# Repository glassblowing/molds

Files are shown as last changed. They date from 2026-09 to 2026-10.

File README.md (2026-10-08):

# Glassblowing mold generators

Parametric molds for hot glass, written as [build123d](https://github.com/gumyr/build123d) scripts. Each script writes ready-to-order files: STEP for a machine shop, DXF for a laser-cutting service, and STL for a look or a test print. The generated files are checked in under [`mold-designs/`](mold-designs/), so you can order parts without running anything.

> [!WARNING]
> **These are designs, not proven tools.** As far as this repository records, none of them has yet been made and used with glass. The scripts check that the parts are valid solids, fit together, and can be reached by a cutter, but nobody has confirmed how they behave at the bench. Treat the sizes as a starting point, and please report back if you build one.

## What is here

| Mold | What it does | How it is made | Script | Files |
|---|---|---|---|---|
| [Insert mold](#insert-mold) | Dip or blow mold with five swappable patterns on loose inserts | CNC milling | `pineapple_mold_generator.py` | `mold-designs/insert-mold/` |
| [Pineapple mold](#pineapple-mold) | One-piece version of the pineapple pattern | Laser-cut plates, or casting | `pineapple_mold_generator.py` | `mold-designs/pineapple/` |
| [Optic molds](#optic-molds) | Classic open dip molds: star, flower, rib, fluted, sunburst | CNC milling | `optic_mold_generator.py` | `mold-designs/optic/` |
| [Blow mold](#blow-mold) | Two-part mold for a vessel shape you draw as a profile | CNC milling | `blow_mold_generator.py` | `mold-designs/blow/` |
| [Segmented grenade mold](#segmented-grenade-mold) | Blow mold of four staves in a square tube, for a grid of raised squares | CNC milling plus stock tube | `segmented_mold_generator.py` | `mold-designs/segmented/` |

## Quick start

The only thing to install is [uv](https://docs.astral.sh/uv/). Each script declares its own dependencies and runs through its shebang:

```sh
./pineapple_mold_generator.py     # about two minutes
./optic_mold_generator.py         # every pattern
./optic_mold_generator.py star rib   # only these
./blow_mold_generator.py
./segmented_mold_generator.py
```

There is also a [just](https://just.systems/) file, so you don't have to remember the script names:

```sh
just                 # list the recipes
just all             # whatever is out of date: the molds, then the README pictures
just pineapple       # one generator: optic, blow, pineapple or segmented
just optic star rib  # only these optic patterns
just previews        # the README pictures
just force=true all  # everything, whether it is out of date or not
```

A generator is skipped when its files are newer than its script. Right after a fresh clone the file times mean nothing, so use `force=true` if you want to be sure.

- **Changing a design:** every script starts with a block of named settings in millimetres, each with a comment. Edit them and run the script again.
- **The report:** each run prints the sizes, weights, stock to buy, and the results of its checks. Read it before ordering; it warns when a setting makes a part that can't be machined or assembled.
- **Viewer:** the scripts finish by sending the parts to the [OCP CAD Viewer](https://github.com/bernhard-42/vscode-ocp-cad-viewer) for VS Code. Without the viewer running they print a connection error at the very end. The files are already written by then, so it can be ignored.
- **Pictures:** `./render_previews.py` redraws the images in this README from the generated STL files. `just all` does this after the molds.

## Insert mold

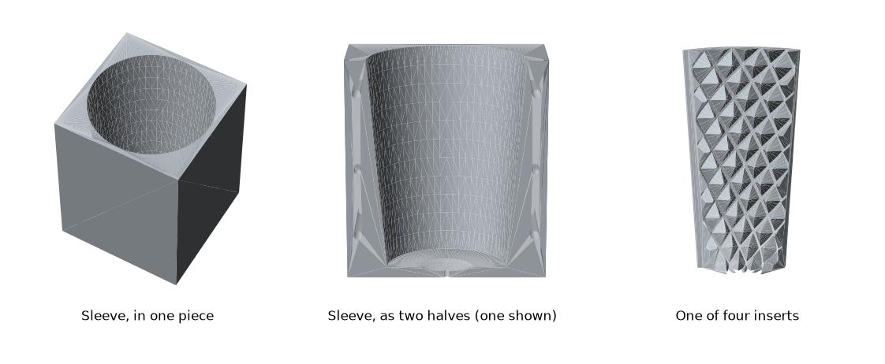
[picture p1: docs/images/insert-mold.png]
The sleeve in one piece, one half of the split sleeve, and one insert


The pattern is not cut into the mold body. It is on four identical loose inserts, each a quarter of the wall, that drop into a sleeve with a tapered bore.

- **Snug but removable:** the inserts wedge into the taper under their own weight with no play, and are free the moment they lift. Hot inserts that have grown sit a little higher instead of jamming.
- **Nothing gets stuck:** if the glass chills and grabs the pattern, pulling it out brings the inserts with it, and they pull off sideways.
- **Registered seams:** a small step down each seam laps every insert over its neighbor, so none can drop inward, yet each still pulls straight off.
- **Curved bottom:** the wall curves in like a bowl and the pattern carries on round it, so the rounded end of a bubble meets the same pattern as its sides. The sleeve's floor is dished and vented so the glass can't seal to it.
- **Swappable:** all five insert sets fit the same sleeve.

### Insert sets

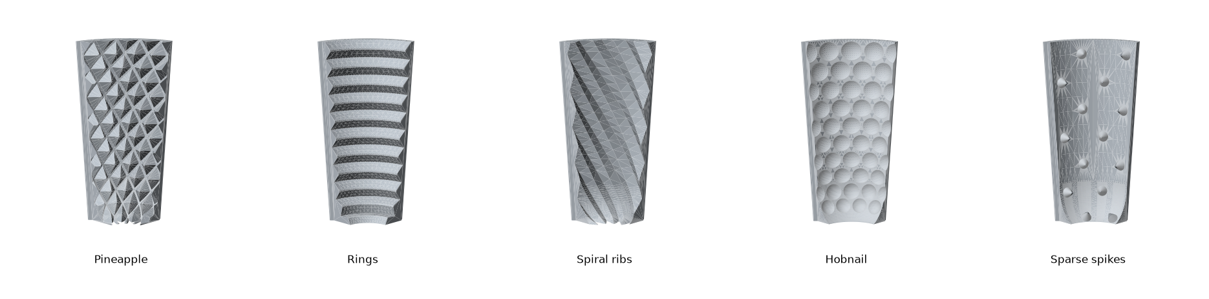
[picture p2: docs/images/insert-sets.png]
The five insert sets, seen from inside the mold


| Set | File | Pattern | In the glass | Cutter directions |
|---|---|---|---|---|
| Pineapple | `inserts/pineapple.step` | 14 rows of 16 diamond pyramids with small flat tips, about 3 to 9 mm deep, leaning into a spiral | A grid of dimples; gather over them to trap bubbles | 3 |
| Rings | `inserts/rings.step` | 11 V-shaped rings, 12 mm apart and 5 mm deep | Grooves round the piece | 2 |
| Spiral ribs | `inserts/spiral.step` | 16 ribs turning 120° from floor to rim | A swirl optic without twisting by hand | 2 |
| Hobnail | `inserts/hobnail.step` | 160 round pockets, 9 to 12.7 mm across; those on a seam are half in each insert | Rows of raised beads; blow into the mold to fill them | 2 |
| Sparse spikes | `inserts/spikes.step` | 56 cones, 7 mm tall | A few deep pits, for deliberate air-trap bubbles | 4 |

Make four of whichever set you want. "Cutter directions" is how many angles the cutter has to come from to reach the whole pattern: square-on to the insert's inside face, then turned to each side or tipped toward the floor. On a machine with a rotary axis these are index positions in one setup; on a plain 3-axis mill each is a separate tilted setup. The script works this out by line of sight and prints the share of the surface reached.

Rings and spiral ribs hold the glass against a straight pull, so expect those inserts to come out with the glass. Pineapple and spikes rely on the glass touching only the tips.

### Parts to order

| Part | Quantity | File | Stock | Notes |
|---|---|---|---|---|
| Insert | 4 of one set | `inserts/<set>.step` | about 65 × 37 × 122 mm each | The outside is the taper seat |
| Sleeve, one piece | 1 | `sleeve_solid.step` | 100 × 100 × 130 mm block | Bore is milled 126 mm deep from the top |
| Foot plate | 1 | `foot_plate_solid.dxf` | 130 × 130 × 8 mm plate | Sticks out 15 mm to stand on |
| M5 screws | 4 | | | Foot plate to the underside of the sleeve; countersink them |

The sleeve is also drawn as two halves, to quote against the one-piece version. Use one or the other:

| Part | Quantity | File | Stock | Notes |
|---|---|---|---|---|
| Sleeve half | 2 | `sleeve_half_a.step`, `sleeve_half_b.step` | 116 × 50 × 130 mm block each | Each half-bore is a trough 46 mm deep |
| Foot plate | 1 | `foot_plate_halves.dxf` | 146 × 130 × 8 mm plate | |
| M5 bolts and nuts | 4 | | at least 110 mm long | Through the split |
| Dowel pins | 2 | | 4 mm | Line the halves up |
| M5 screws | 4 | | | Foot plate |

Things to tell the shop:

- **Material:** 6061 aluminum machines cleanly and is the default. See [Materials](#materials).
- **Outside of the sleeve:** leave it as sawn. Only the bore, the floor and the holes matter.
- **Creases:** the sharp inside creases of every pattern may be left rounded to the cutter's radius. The glass never reaches them.
- **The files are true CAD surfaces, not converted meshes.** Walls are real cones, pockets real spheres, and rib flanks smooth curved surfaces. On the pineapple insert each point is a flat-sided boss with a flat tip, standing on the smooth wall with a strip of bare wall round it. Upload the `.step` files; the `.stl` files are meshes and a shop will reject them.
- **The taper:** the bore and the backs of the inserts are the same cone, 5.1° a side. An error of 0.1 mm in a diameter only moves the inserts 0.6 mm up or down, and they are designed to stand 1.5 mm clear of the floor to absorb it.
- **Split sleeve only:** the two half-bores must meet without a step.

### Size

| | |
|---|---|
| Cavity at the rim | 82 mm |
| Flat floor | 32 mm |
| Cavity depth | 124 mm |
| Opening between pineapple tips | 25 mm at the bottom, 63 mm at the rim |
| Sleeve | 100 mm square, 130 mm tall |

The main settings are `MOLD_DIAMETER`, `MOLD_HEIGHT`, `BOTTOM_RADIUS`, `FLOOR_RADIUS` and `BOWL_HEIGHT`. Each insert set has its own block of settings below those.

## Pineapple mold

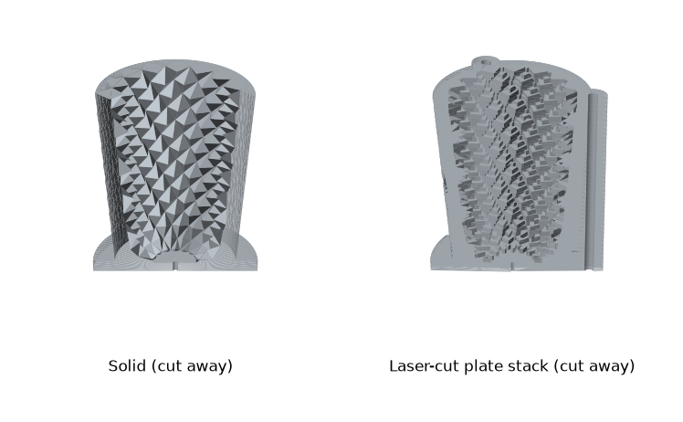
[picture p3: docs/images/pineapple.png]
The solid pineapple mold and the laser-cut plate stack, both cut away


The same pineapple cavity as the insert set, as a one-piece mold with a tapered body and a foot. It is drawn two ways.

**Laser-cut plate stack.** The cavity is sliced into flat plates that stack on threaded rods. The points come out stepped, and overhangs cost nothing because every plate is cut on its own.

| Part | Quantity | File | Notes |
|---|---|---|---|
| Plates | 41 | `plates/plate_01.dxf` to `plate_41.dxf` | 3.175 mm (1/8") sheet, up to 113 mm across, numbered from the bottom |
| M6 threaded rod | 3 | | at least 150 mm long, with nuts |

- **Order and alignment:** the rod holes are unevenly spaced, so a plate only fits one way round and one way up. Each plate also has a notch in its rim, a little further round than the one below, so a correctly ordered stack shows one diagonal line of notches.
- **Cost drivers:** 0.47 m² of sheet and 30 m of cut. The script prints these so you can compare variations.
- **Check before ordering:** the 6.4 mm rod holes and the 3.2 mm vent against your service's minimum hole size for the sheet you choose.

**Solid.** `solid.step` is one piece with true pyramids, for casting or metal printing. It cannot be milled: the points overhang, so a cutter working from above can't reach under them.

## Optic molds

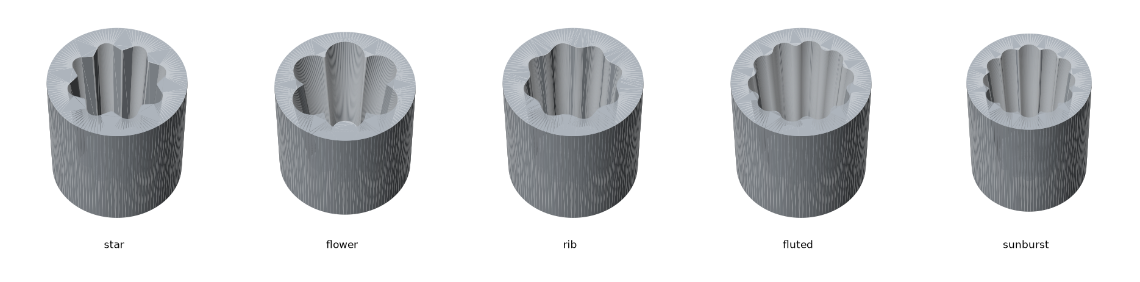
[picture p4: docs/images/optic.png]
The five optic molds


One-piece open dip molds. The gather is pushed in to take the pattern and pulled straight out, so every cavity widens toward the top with at least 3° of draft.

| Pattern | Cavity | Bar stock |
|---|---|---|
| `star` | 67 → 82 mm, 100 mm deep | 4.5" round × 118 mm |
| `flower` | 74 → 103 mm, 100 mm deep | 5" round × 118 mm |
| `rib` | 69 → 82 mm, 100 mm deep | 4.5" round × 118 mm |
| `fluted` | 68 → 87 mm, 100 mm deep | 4.5" round × 118 mm |
| `sunburst` | 58 → 77 mm, 100 mm deep | 4" round × 118 mm |

The script is built around machining cost. It rounds the pocket corners to suit the cutter you name in `TOOL_DIAMETER`, picks the smallest standard bar that leaves enough wall, and reports the largest cutter that can finish each shape and how far it has to reach.

## Blow mold

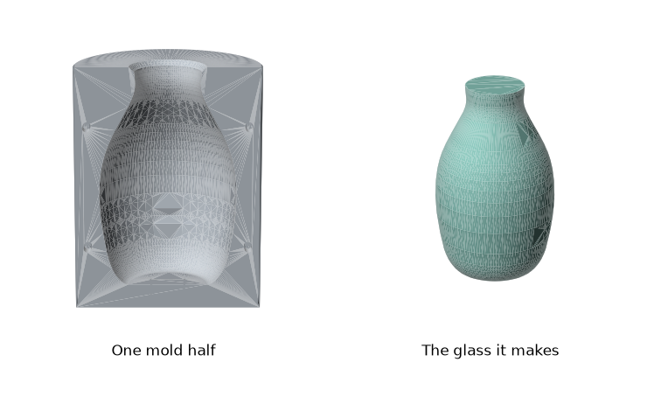
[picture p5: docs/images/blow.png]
One half of the blow mold and the glass it makes


A two-part mold for a vessel. You describe the outside of the finished piece as a list of (radius, height) points in `PROFILE`, and the script fits a smooth curve through them, scales it for shrinkage, and splits the block into two halves with dowel holes and vents.

## Segmented grenade mold

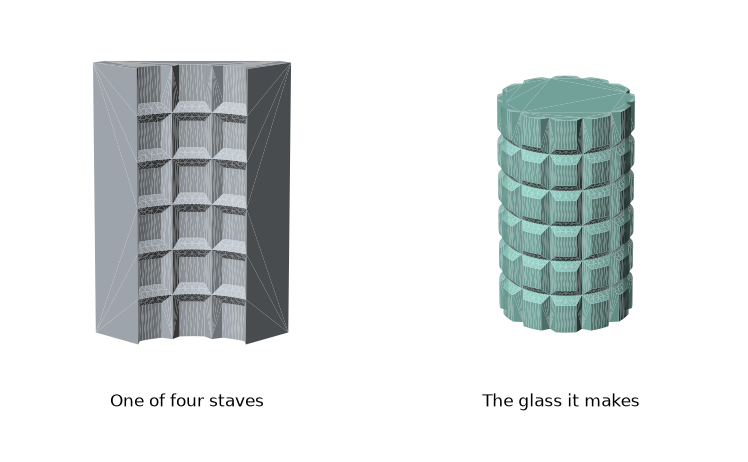
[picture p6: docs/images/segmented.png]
One stave of the segmented mold and the glass it makes


A blow mold for a grid of raised squares. Four identical staves stand in a length of square steel tube. The glass is blown out against them, and lifting the pipe brings the staves up with it so they fall away sideways. Each stave is machined square-on from its inside face.

| Part | Quantity | File | Notes |
|---|---|---|---|
| Stave | 4 | `stave.step` | from 71 × 20 × 100 mm bar |
| Square steel tube | 1 | | 3.5" × 3/16" wall, 100 mm long |
| Base plate | 1 | `base_plate.dxf` | 119 mm square, 6.35 mm; weld or bracket it to the tube |

The tube's real inside size and corner radius vary by supplier. Measure yours and adjust `TUBE_OUTER`, `TUBE_WALL` and `CORNER_RELIEF` before cutting staves.

## Materials

- **6061 aluminum:** the default for machined parts. It works even though it melts below glass working temperature, because contact is brief and aluminum carries the heat away quickly.
- **5052 aluminum:** fine for laser-cut plates, where it is a common sheet alloy. It is gummier to machine, so prefer 6061 for inserts and sleeves.
- **Mild steel:** a good choice for laser-cut plates and for anything with thin points, which stay harder when hot.
- **Never galvanized steel.** It gives off zinc fumes at glass temperatures.

Aluminum loses its hardness once it has spent time well above 200 °C, so points and edges get easier to dent with use.

## Using the molds

- **Keep contact short.** Don't let hot glass sit in a metal mold, and let the mold cool between dips. A mold that gets too hot makes glass stick; a stone-cold one leaves chill marks.
- **Glass still needs annealing.** Take the piece out as soon as it is stiff and put it away to anneal. Glass left to go cold in a metal mold will crack.
- **Loose inserts and staves come out hot.** Have tongs and somewhere safe to drop them.
- **Deep molds chill the bottom first** when the gather is simply plunged in. Blowing the bubble out against the wall makes the contact much more even.

## How the designs are checked

The scripts refuse to write parts that fail these, or print a warning in the report:

- **Valid solids:** every part is a single closed solid.
- **Release:** the optic molds and the segmented staves are checked for draft, so nothing hides behind anything else in the direction the glass or the part pulls away.
- **Fit:** four inserts must add up exactly to a full ring. This catches a pattern that doesn't repeat every quarter turn, and cuts that have gone wrong.
- **Cutter reach:** for the insert sets, the share of the patterned surface a cutter can see from the directions listed in the settings.

These are checks on geometry. They don't replace a machinist's judgement or a trial with glass.

## License

MIT. See [LICENSE](LICENSE).

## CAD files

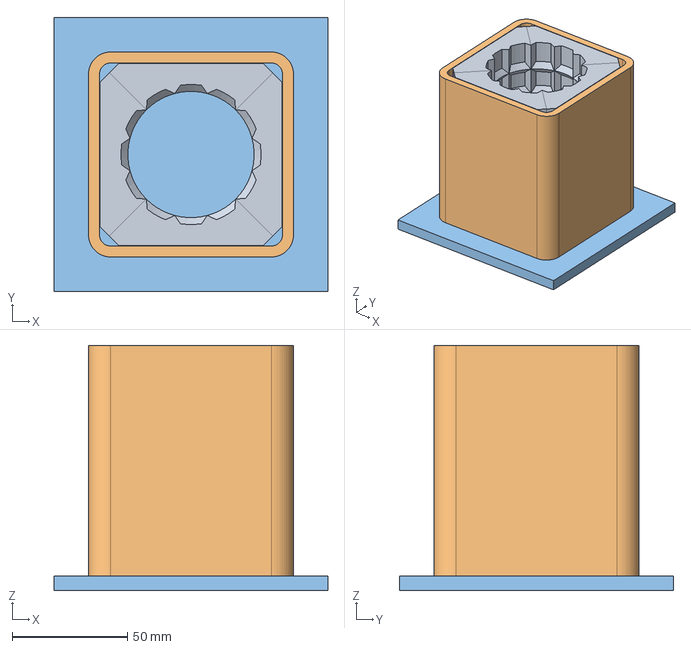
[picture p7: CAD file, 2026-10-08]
mold-designs/segmented/assembly.step
118.9 x 118.9 x 106.3 mm

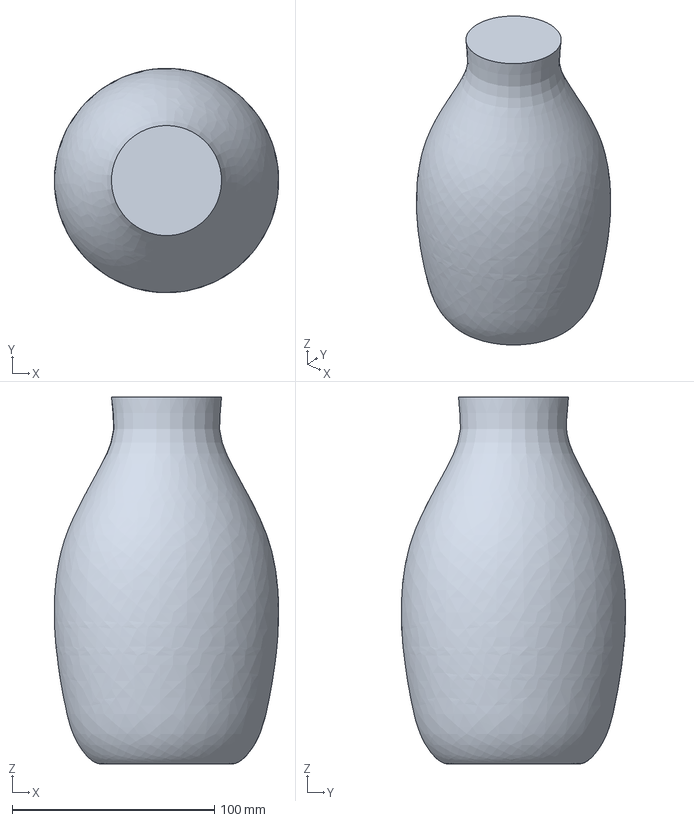
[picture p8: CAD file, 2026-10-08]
mold-designs/blow/glass_piece.step
110.8 x 110.9 x 181.3 mm

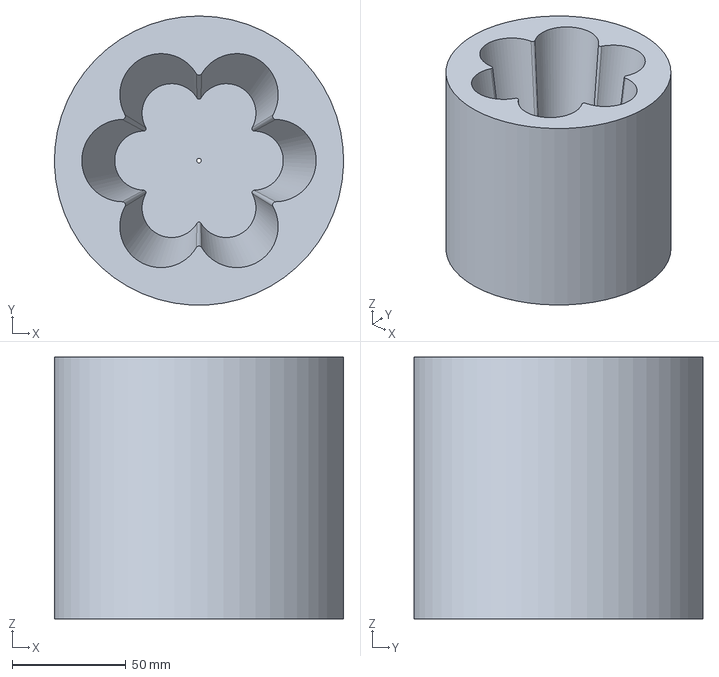
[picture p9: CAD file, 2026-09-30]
mold-designs/flower.step
126.9 x 126.9 x 115.0 mm

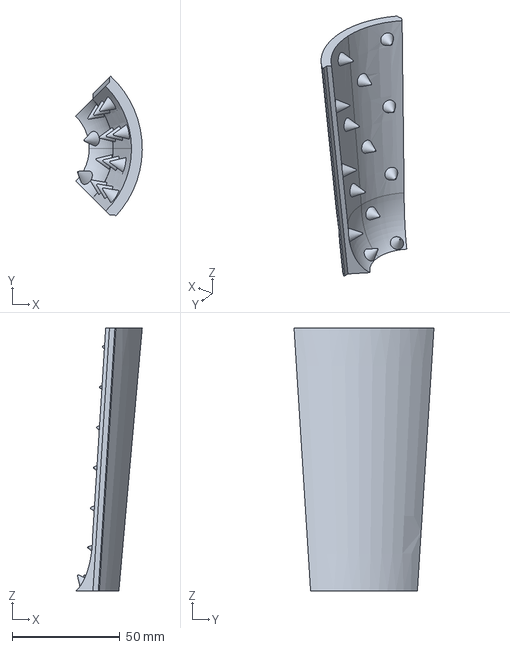
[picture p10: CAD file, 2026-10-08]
mold-designs/insert-mold/inserts/spikes.step
30.9 x 65.0 x 122.2 mm

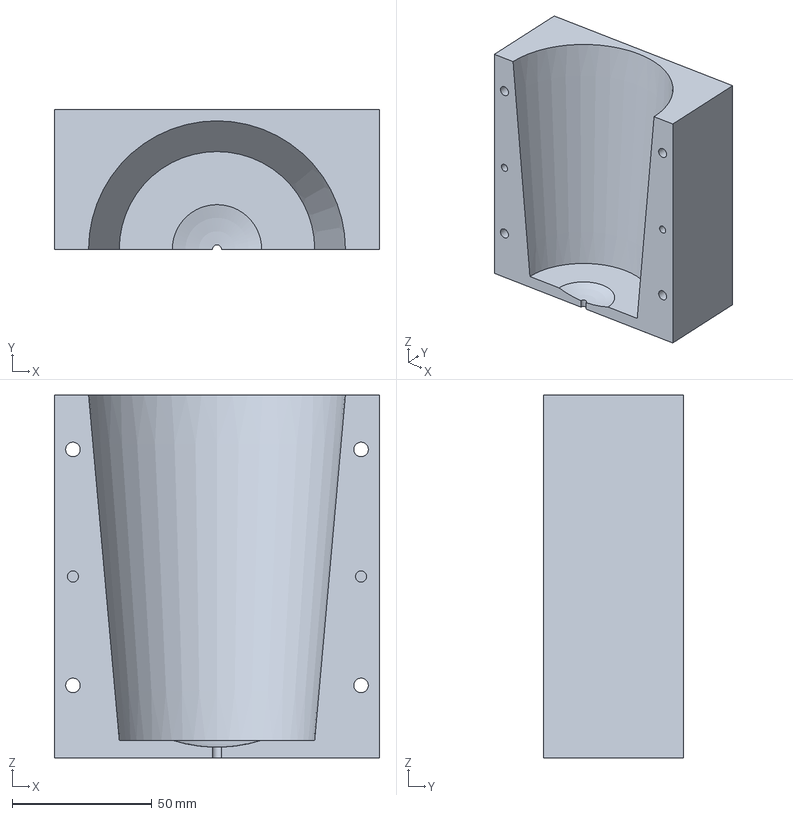
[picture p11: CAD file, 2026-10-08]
mold-designs/insert-mold/sleeve_half_b.step
116.4 x 50.0 x 130.0 mm

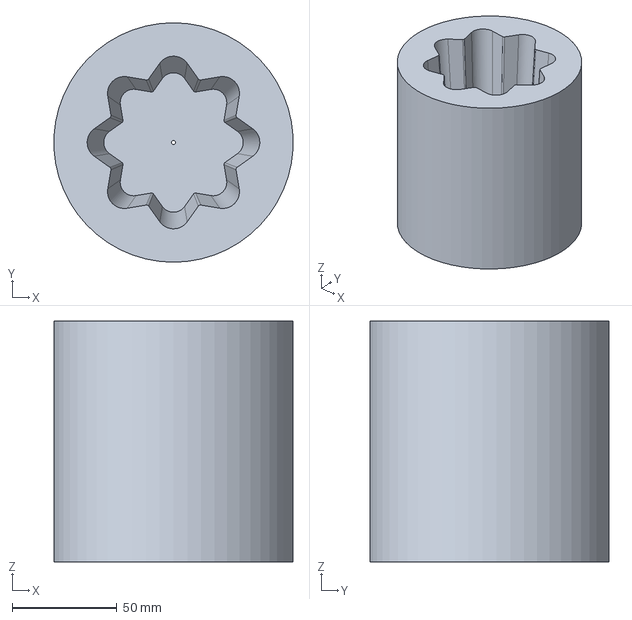
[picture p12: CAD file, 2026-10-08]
mold-designs/optic/star.step
114.1 x 114.3 x 115.0 mm

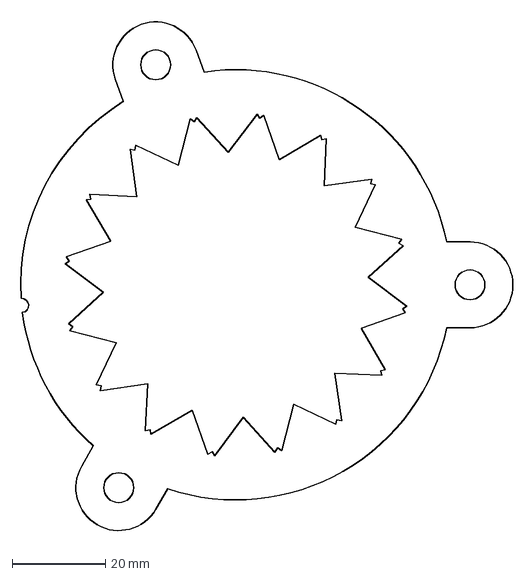
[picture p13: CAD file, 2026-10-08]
mold-designs/pineapple/plates/plate_27.dxf
106.5 x 111.5 mm

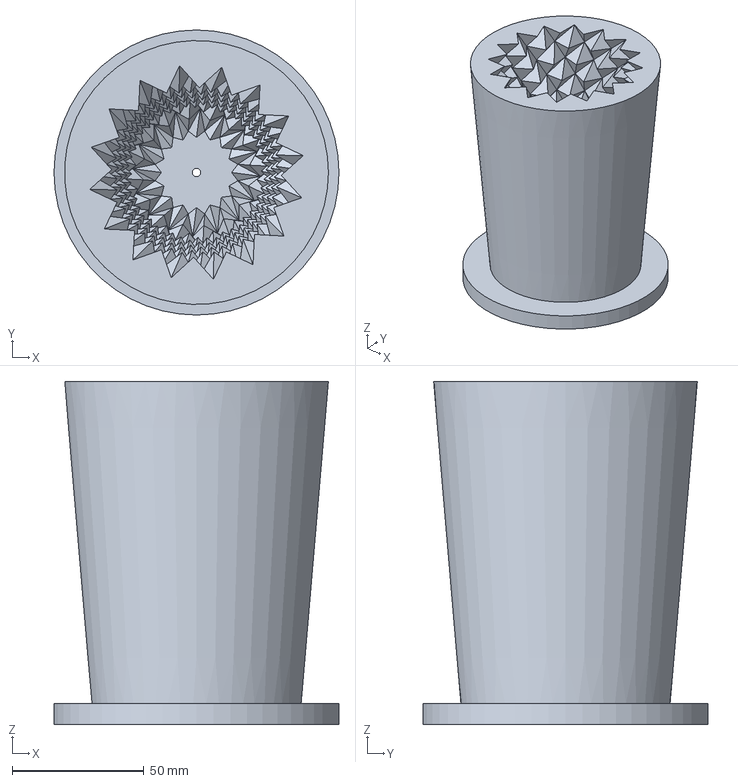
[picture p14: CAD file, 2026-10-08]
mold-designs/pineapple/solid.step
108.0 x 108.0 x 130.0 mm

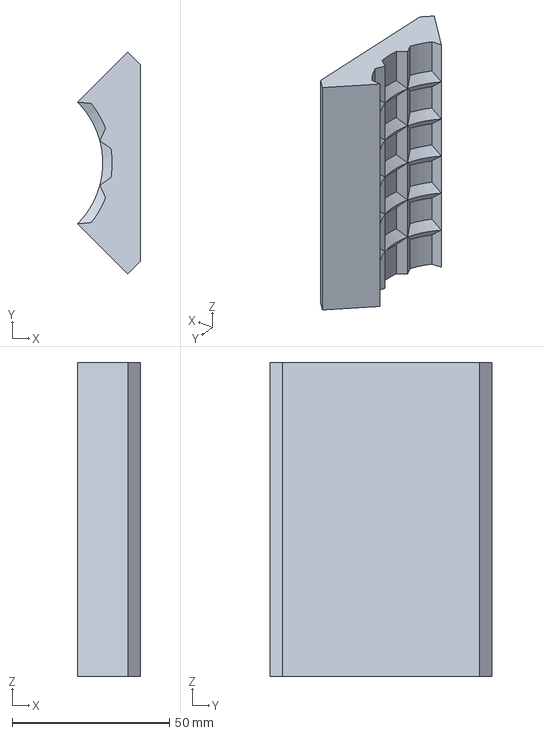
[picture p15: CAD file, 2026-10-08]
mold-designs/segmented/stave.step
20.0 x 70.8 x 100.0 mm

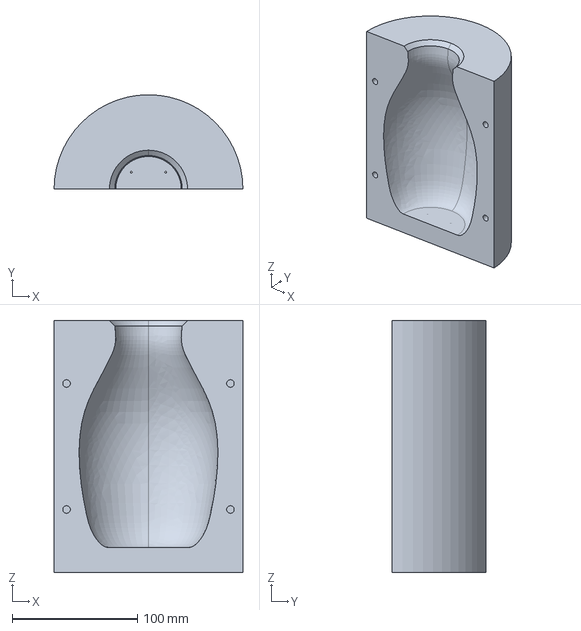
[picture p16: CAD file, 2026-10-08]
mold-designs/blow/mold_half_b.step
150.9 x 75.5 x 201.3 mm

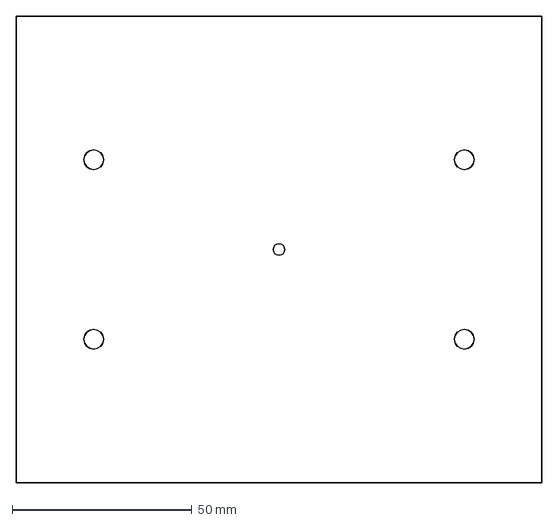
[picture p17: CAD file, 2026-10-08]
mold-designs/insert-mold/foot_plate_halves.dxf
146.4 x 130.0 mm

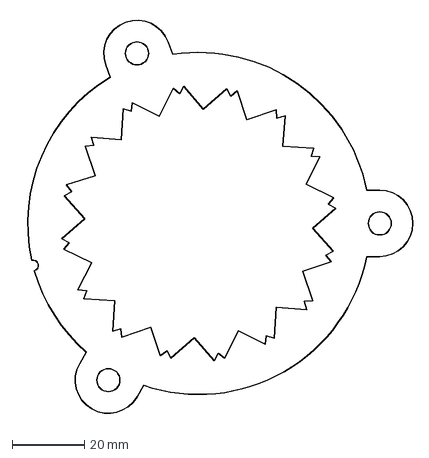
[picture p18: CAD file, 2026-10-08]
mold-designs/pineapple/plates/plate_32.dxf
110.1 x 111.5 mm

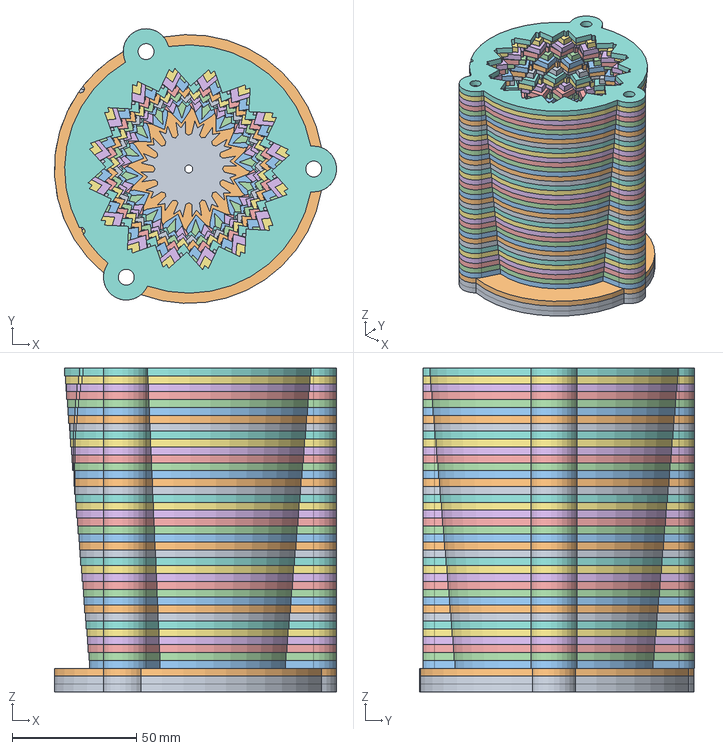
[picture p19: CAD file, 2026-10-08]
mold-designs/pineapple/stack.step
113.4 x 110.3 x 130.2 mm

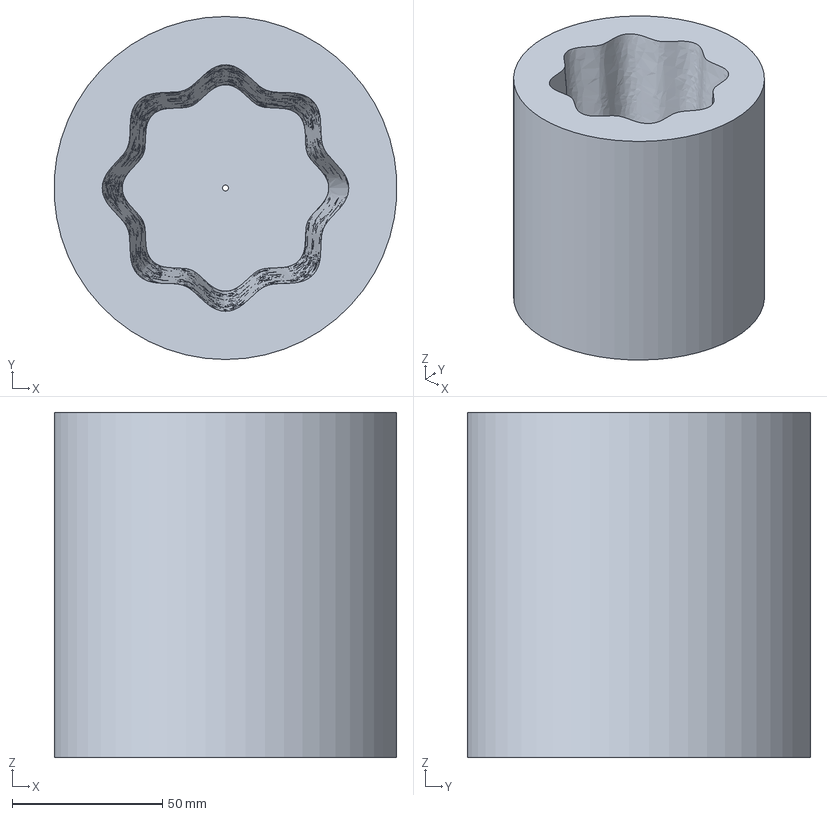
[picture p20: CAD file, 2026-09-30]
mold-designs/rib.step
114.1 x 114.3 x 115.0 mm

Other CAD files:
mold-designs/insert-mold/inserts/hobnail.step
mold-designs/optic/flower.step
mold-designs/blow/mold_half_a.step
mold-designs/insert-mold/foot_plate_solid.dxf
mold-designs/blow/glass_piece.stl
mold-designs/blow/mold_half_a.stl
mold-designs/blow/mold_half_b.stl
mold-designs/fluted.step
mold-designs/glass_piece.step
mold-designs/insert-mold/inserts/hobnail.stl
mold-designs/insert-mold/inserts/pineapple.step
mold-designs/insert-mold/inserts/pineapple.stl
mold-designs/insert-mold/inserts/rings.step
mold-designs/insert-mold/inserts/rings.stl
mold-designs/insert-mold/inserts/spikes.stl
mold-designs/insert-mold/inserts/spiral.step
mold-designs/insert-mold/inserts/spiral.stl
mold-designs/insert-mold/sleeve_half_a.step
mold-designs/insert-mold/sleeve_half_a.stl
mold-designs/insert-mold/sleeve_half_b.stl
mold-designs/insert-mold/sleeve_solid.step
mold-designs/insert-mold/sleeve_solid.stl
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

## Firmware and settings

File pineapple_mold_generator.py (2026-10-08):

#!/usr/bin/env -S uv run --python 3.13 --script --no-cache
# /// script
# requires-python = "==3.13"
# dependencies = [
#   "build123d",
#   "numpy",
#   "ocp-vscode"
# ]
# ///

"""Twisted pineapple optic mold, built with build123d.

A pineapple mold is a dip mold whose wall is covered in diamond-shaped pyramids,
packed edge to edge, that press a grid of dimples into the gather. Turning each
row a little further than the one below leans the diamonds over, so the pattern
spirals around the cavity.

The points are as deep as POINT_DEPTH asks, in the manner of cast bronze
pineapple molds: on a nearly straight wall their undersides overhang. That works
because the glass only ever touches the tips, never the wall between them, so
there is nothing for an overhang to trap. It does mean the points can't be
milled from above.

The bottom of the cavity curves in like a bowl and the points carry on round
it, shrinking as they go, so the rounded end of a bubble meets the same pattern
as its sides. Only a small flat floor is left in the middle, for the vent.

The same cavity is built four ways:

Stacked plates, for laser cutting. The cavity is sliced into flat rings, so the
pyramids come out stepped; thinner plates follow them more closely. Overhangs
cost nothing here, because every plate is cut on its own. Floor spikes can't be
cut this way, since each would be a loose island, so the base plates get a hole
at each one to tap for a cone-point set screw instead. The plates follow the
mold's taper, with a lug reaching out to each rod, which uses less sheet and
less cutting than plain discs big enough to hold the rods.

Solid, for casting or metal printing. One piece with true pyramids, a thin even
wall that tapers with the cavity, and a foot. Both are priced by the metal used.

Inserts in a sleeve, for CNC machining. The points are on four identical loose
inserts, each a quarter of the wall, that drop into a sleeve with a tapered
bore. A cutter comes at each insert from its open inside face, turned a little to
either side to get behind the points. The taper is what makes the fit work: the
inserts wedge snug under their own weight, with no play, and are free the moment
they lift. If the glass chills and grabs the points, pulling it out brings the
inserts with it and they peel off sideways. A small step down each seam laps
every insert over its neighbor, so none can drop inward, yet each still pulls
straight off. Hot inserts that have grown just sit
a little higher in the taper instead of jamming, as they would in a straight
bore. The sleeve's floor is dished, with a vent, so the glass can't seal to it.
Four more sets of inserts fit the same sleeve in place of the pineapple ones:

Rings running round the cavity.
Spiral ribs, which give a swirl without twisting the glass by hand.
Hobnail, round pockets that the glass is blown into to raise rows of beads.
Sparse spikes, a few tall points for deliberate air-trap bubbles.

Rings and spiral ribs hold the glass against a straight pull far more than
points do, which is what the loose inserts are for: they come out with the glass
and pull off sideways.

The sleeve is drawn two ways for a mill, to quote against each other: as one
square block with the bore milled down from the top, and as two blocks bolted
together, whose bore is two shallow troughs instead of one deep hole.

Rings, also for CNC machining. The solid cut into short rings that bolt together, each
shallow enough for a ball end mill to finish from above on a 3-axis machine.
Only written when the points are shallow enough not to overhang.

The outsides differ, which is fine for heat. A dip lasts a second or two, and in
that time heat gets only about 10 mm into aluminum and 5 mm into steel, so how
evenly the glass is chilled is set by the points, which are the same all the way
round. Between dips the metal evens itself out, within seconds in aluminum and
about a minute in steel. Metal further out only adds heat capacity, which slows
how fast the mold warms up over a session.

Run:
    ./pineapple_mold_generator.py

Outputs go to ./mold-designs/:
    pineapple/solid.step             the one-piece mold
    pineapple/plates/plate_NN.dxf    one cutting file per plate, numbered from the bottom
    pineapple/stack.step             the assembled plates (reference)
    pineapple/cnc_rings/ring_N.step  one part per ring, if the points allow it
    insert-mold/inserts/<set>.step   one insert of each set; make four
    insert-mold/sleeve_solid.step    the sleeve the inserts drop into, in one piece
    insert-mold/sleeve_half_X.step   the same sleeve as two halves
    insert-mold/foot_plate_*.dxf     the foot that screws under each sleeve
    *.stl                            the same parts as meshes
"""

import math
from pathlib import Path

import numpy as np

from build123d import (
    Align,
    Axis,
    Box,
    Circle,
    Compound,
    Cone,
    Cylinder,
    EllipticalCenterArc,
    ExportDXF,
    Face,
    Plane,
    Polygon,
    Polyline,
    Pos,
    Rectangle,
    Rot,
    Shell,
    Solid,
    Sphere,
    Unit,
    Vector,
    Wire,
    export_step,
    export_stl,
    extrude,
    make_face,
    revolve,
)
from ocp_vscode import show

# --- Mold (all units mm) --------------------------------------------------------
# Outside of the mold at its rim. The cavity fills it, less SOLID_WALL around the
# rim and the base underneath, and tapers down to BOTTOM_RADIUS at the floor. The
# outside tapers with it, so the wall stays about SOLID_WALL thick.
MOLD_DIAMETER = 100.0
MOLD_HEIGHT = 130.0
# Metal around the cavity, measured at the creases between points. The points
# themselves add to it, so this can be thin. In the sleeved version it is shared
# between the sleeve's rim and the inserts.
SOLID_WALL = 9.0
# Cavity wall radius the taper would reach at the floor. Smaller gives more
# taper, which is also the taper the inserts seat on.
BOTTOM_RADIUS = 30.0
# Below this height the wall curves in to meet the floor, like the bottom of a
# bowl. 0 leaves a straight wall and a flat floor.
BOWL_HEIGHT = 28.0
# Flat floor left in the middle of the bowl. The points get smaller toward it,
# so it can't shrink to nothing.
FLOOR_RADIUS = 16.0
# Flange around the bottom to stand on, so the mold stays down while the glass
# is pulled out.
FOOT_WIDTH = 15.0      # how far it sticks out past the body
FOOT_THICKNESS = 8.0
VENT_DIAMETER = 3.2    # air vent through the base; 0 to omit

# --- Pattern --------------------------------------------------------------------
POINTS_PER_ROW = 16
# Height of each diamond divided by its width, halfway up the cavity. The actual
# value is adjusted slightly so whole rows fit the cavity.
DIAMOND_ASPECT = 1.3
# How far each tip stands in from the wall, as a fraction of its diamond's width.
POINT_DEPTH = 0.6
# How far each row is turned from the row below, as a fraction of the spacing
# between points. 0.5 is the classic upright diamond; moving away from 0.5 leans
# the diamonds into a spiral, one way below 0.5 and the other way above.
TWIST_PER_ROW = 0.35
# Where the tip sits between the middle of the diamond (0) and its top corner
# (1). Raising it steepens the underside, which reduces the overhang.
TIP_LIFT = 0.0
# Grid of square pyramids on the flat floor, as wide as the bottom row's diamonds
# and as deep in proportion. Not in the sleeved version.
FLOOR_SPIKES = False

# --- Stacked plates -------------------------------------------------------------
# Sheet you will have cut. 3.175 is 1/8", stocked by most laser services in
# aluminum and mild steel, and gives each point several steps; 6.35 halves the
# plate count but leaves the points blocky. Never use galvanized steel.
PLATE_THICKNESS = 3.175
# Solid plates under the cavity floor. The solid mold's base is as thick.
BASE_PLATES = 2
# Hole through the base plates at each floor spike, to tap for a cone-point set
# screw that stands up into the cavity.
FLOOR_SCREW_TAP_DRILL = 5.0   # tap M6
# Threaded rods clamp the stack and line the plates up. The holes are unevenly
# spaced so a plate only fits one way round and one way up.
BOLT_HOLE_DIAMETER = 6.4   # close fit for M6
BOLT_ANGLES_DEG = (0, 110, 240)
EDGE_MARGIN = 6.0          # metal between a bolt hole and the cavity or the rim
# Each plate gets a notch in its rim, a little further round than the plate
# below, so a correctly ordered stack shows one diagonal line of notches.
NOTCH_RADIUS = 1.5
NOTCH_START_DEG = 140
NOTCH_SPAN_DEG = 70        # must stay between two bolt holes

# --- Inserts in a sleeve, for CNC machining -------------------------------------
# Loose inserts the wall is divided into. POINTS_PER_ROW must be a multiple of
# this, so that they are all the same part.
INSERT_COUNT = 4
# Sleeve wall at the rim. The sleeve's outside is straight, so its wall is
# thicker lower down. The rest of SOLID_WALL is the thickness of the inserts.
SLEEVE_RIM_WALL = 4.0
# For the sleeve made as two halves: bolts through the split, in a flange down
# each side of the bore, at these fractions of the mold's height. A dowel pin
# sits between them on each side. The inserts' seams don't line up with the split.
SLEEVE_BOLT_HOLE_DIAMETER = 5.2   # close fit for M5
SLEEVE_BOLT_HEIGHTS = (0.2, 0.85)
SLEEVE_DOWEL_DIAMETER = 4.0
SLEEVE_DOWEL_DEPTH = 8.0          # into each half
# Size of the step in each seam, halfway through the insert's wall. On one side
# of an insert it is a lip, on the other a matching rebate. Its faces run along
# and across the directions the two inserts pull off in, so it never binds, and
# the cutter that does the points can cut it.
SEAM_STEP = 2.5
# How far the inserts stand clear of the sleeve's floor when seated, so that the
# taper locates them and not the floor. It also absorbs error in the diameters.
INSERT_FLOOR_GAP = 1.5
FLOOR_DISH = 2.5       # how deep the sleeve's floor is dished at the middle
# Directions the cutter comes at an insert from, each as (turn, tip) in degrees.
# Turn is to either side of square-on to the insert's inside face, about the
# mold's axis; more turns reach further behind the points. Tip is down toward
# the floor. Each direction is another index of a rotary axis or another tilted
# setup.
INSERT_TOOL_DIRECTIONS_DEG = ((0, 0), (-40, 0), (40, 0))
# On the inserts each point is a separate flat-sided boss standing on the smooth
# wall, not a facet of a wall made entirely of triangles. Shops reject the
# all-triangle form as an unmeasurable mesh. A strip of bare wall is left round
# every point, this share of the diamond's width, which is also where the cutter
# runs; and the tip is cut off flat, this share of the way down, so it doesn't
# fold over.
POINT_GAP = 0.15
POINT_TIP_FLAT = 0.1

# --- Ring inserts ---------------------------------------------------------------
# A second set of inserts for the same sleeve: V-shaped rings round the cavity,
# carrying on round the bowl as circles on the bottom.
RING_PITCH = 12.0      # spacing of the rings up the wall, adjusted to fit a whole number
RING_DEPTH = 5.0       # how far each ring stands in from the wall
RING_CREST = 1.0       # flat along the top of each ring, so it doesn't chip
# Rings face the cutter all the way round, so square-on does the wall. The
# second direction, tipped down, is for the rings on the bottom of the bowl.
RING_TOOL_DIRECTIONS_DEG = ((0, 0), (0, 50))

# --- Spiral rib inserts ---------------------------------------------------------
# V-shaped ribs that wind up the wall and in across the bowl.
SPIRAL_RIBS = 16           # must be a multiple of INSERT_COUNT
SPIRAL_TURN_DEG = 120.0    # how far each rib turns about the axis from floor to rim
SPIRAL_DEPTH = 0.35        # how far a rib stands in, as a fraction of the rib spacing
SPIRAL_TOOL_DIRECTIONS_DEG = ((0, 0), (0, 50))

# --- Hobnail inserts ------------------------------------------------------------
# Round pockets in the wall, in staggered rows. Blown into, each raises a bead.
HOBNAIL_PER_ROW = 16       # must be a multiple of INSERT_COUNT
HOBNAIL_FILL = 0.8         # pocket width as a share of the spacing between pockets
# Pocket depth as a fraction of its radius. Up to about 0.4 an insert still pulls
# straight off the beads and is cut square-on; deeper pockets near the seams hook
# behind the beads, and need the cutter turned to each side.
HOBNAIL_DEPTH = 0.35
# The staggered rows put a pocket on every seam between inserts. True cuts those
# half into each insert, so the pattern runs unbroken round the glass, but each
# insert then has half-pockets running out to a sharp edge down both sides, and
# the two halves of a bead only line up as well as the inserts seat. False
# leaves those pockets out, which gives a plain stripe at each seam instead.
HOBNAIL_SPLIT_ON_SEAMS = True
HOBNAIL_TOOL_DIRECTIONS_DEG = ((0, 0), (0, 50))

# --- Sparse spike inserts -------------------------------------------------------
# A few tall cones standing square off the wall, in staggered rows.
SPIKES_PER_ROW = 8         # must be a multiple of INSERT_COUNT
SPIKE_ROW_SPACING = 18.0   # between rows, measured up the wall
SPIKE_HEIGHT = 7.0
SPIKE_BASE_DIAMETER = 7.0
SPIKE_TIP_DIAMETER = 0.6   # a small flat so the tip doesn't fold over
SPIKE_TOOL_DIRECTIONS_DEG = ((0, 0), (-40, 0), (40, 0), (0, 50))
# Holes in the underside of the sleeve for the screws that hold the foot plate.
FOOT_TAP_DRILL = 4.2       # tap M5
FOOT_TAP_DEPTH = 10.0

# --- Rings for CNC machining ----------------------------------------------------
# Used only when the points don't overhang. The pyramids are finished with a
# ball end mill working down from the top of each ring. The creases between pyramids come out rounded to the cutter's
# radius, which the glass never touches. A smaller cutter leaves crisper creases
# but reaches less far, so it needs more rings, and every ring is another part
# and another setup: this is the main cost control. 12 gives 3 rings, 6 gives 5.
CNC_TOOL_DIAMETER = 12.0
# Deepest a cutter may reach, in cutter diameters. Around 8 is a long-reach
# cutter that still cuts well; much more chatters and gets expensive.
CNC_MAX_REACH = 8.0
# Rods run through the rim wall of every ring to clamp them and line them up.
# They have to fit inside SOLID_WALL, so they are smaller than the plate stack's.
RING_BOLT_HOLE_DIAMETER = 5.2   # close fit for M5

# Density in g/cm^3 and specific heat in J/(g K), for the weight and heat
# capacity in the report. More heat capacity means the mold warms up more slowly
# over repeated dips.
MATERIALS = {"aluminum": (2.70, 0.90), "steel": (7.85, 0.49)}

OUT_DIR = Path(__file__).parent / "mold-designs"

BASE_THICKNESS = BASE_PLATES * PLATE_THICKNESS
CAVITY_DEPTH = MOLD_HEIGHT - BASE_THICKNESS
TOP_RADIUS = MOLD_DIAMETER / 2 - SOLID_WALL
CONE_SLOPE = (TOP_RADIUS - BOTTOM_RADIUS) / CAVITY_DEPTH
CONE_ANGLE_DEG = math.degrees(math.atan(CONE_SLOPE))
# The stack is built from whole plates, so it comes out within half a plate of
# MOLD_HEIGHT.
CAVITY_PLATES = round(CAVITY_DEPTH / PLATE_THICKNESS)
PLATE_COUNT = BASE_PLATES + CAVITY_PLATES
BODY_BOTTOM_RADIUS = BOTTOM_RADIUS + SOLID_WALL
INSERT_WALL = SOLID_WALL - SLEEVE_RIM_WALL
FOOT_RADIUS = BODY_BOTTOM_RADIUS + FOOT_WIDTH
FOOT_PLATES = max(1, round(FOOT_THICKNESS / PLATE_THICKNESS))
PITCH_DEG = 360 / POINTS_PER_ROW
FLOOR_EDGE = FLOOR_RADIUS if BOWL_HEIGHT > 0 else BOTTOM_RADIUS


def wall_samples():
    """The cavity wall in profile: distance along it, radius and height.

    Distance is measured up the wall from the edge of the floor. The samples run
    on straight down below the floor and up past the rim, so that rows of points
    can overhang both ends and be trimmed flat.
    """
    bowl_top = BOTTOM_RADIUS + BOWL_HEIGHT * CONE_SLOPE
    points = [(FLOOR_EDGE, -2 * MOLD_HEIGHT), (FLOOR_EDGE, 0.0)]
    if BOWL_HEIGHT > 0:
        # A quarter of an ellipse: level where it leaves the floor, upright where
        # it meets the wall.
        for a in np.linspace(0, math.pi / 2, 200)[1:]:
            points.append((
                FLOOR_EDGE + (bowl_top - FLOOR_EDGE) * math.sin(a),
                BOWL_HEIGHT * (1 - math.cos(a)),
            ))
    points.append((BOTTOM_RADIUS + 3 * MOLD_HEIGHT * CONE_SLOPE, 3.0 * MOLD_HEIGHT))
    radius, height = np.array(points).T
    along = np.concatenate([[0], np.cumsum(np.hypot(np.diff(radius), np.diff(height)))])
    return along - along[1], radius, height


WALL_ALONG, WALL_RADIUS, WALL_HEIGHT = wall_samples()
# Distance up the wall from the floor to the rim.
WALL_LENGTH = float(np.interp(CAVITY_DEPTH, WALL_HEIGHT[1:], WALL_ALONG[1:]))
# Rows are evenly spaced up the wall, as near to DIAMOND_ASPECT as a whole number
# allows, taking the diamond width halfway up the straight part.
ROWS = max(1, round(
    WALL_LENGTH
    / (DIAMOND_ASPECT / 2 * (BOTTOM_RADIUS + BOWL_HEIGHT * CONE_SLOPE + TOP_RADIUS)
       * math.sin(math.pi / POINTS_PER_ROW))
))
ROW_PITCH = WALL_LENGTH / ROWS


# --- Diamond pyramids -----------------------------------------------------------


def wall_at(along):
    """Radius and height of the wall at a distance up it from the floor."""
    return (
        float(np.interp(along, WALL_ALONG, WALL_RADIUS)),
        float(np.interp(along, WALL_ALONG, WALL_HEIGHT)),
    )


def row_radius(row):
    """Wall radius at a row's widest corners. Row 0 sits at the edge of the floor."""
    return wall_at(row * ROW_PITCH)[0]


def row_z(row):
    return wall_at(row * ROW_PITCH)[1]


def diamond_width(row):
    return 2 * row_radius(row) * math.sin(math.pi / POINTS_PER_ROW)


def point_depth(row):
    return POINT_DEPTH * diamond_width(row)


def wall_point(radius, angle_deg, z):
    a = math.radians(angle_deg)
    return Vector(radius * math.cos(a), radius * math.sin(a), z)


def pyramid(row, i):
    """Corners of one pyramid: its tip, then the diamond's left, bottom, right, top.

    The side corners sit on this row's ring and the bottom and top corners on the
    rings of the rows below and above, where they are the side corners of those
    rows' diamonds, so the diamonds tile the wall with no gaps. The twist shifts
    the bottom and top corners sideways, which leans the diamond.
    """
    center = (i + row * TWIST_PER_ROW) * PITCH_DEG
    lean = (TWIST_PER_ROW - 0.5) * PITCH_DEG
    # The tip stands square off the wall, which on the bowl means partly upward.
    along = (row + TIP_LIFT) * ROW_PITCH
    (r0, z0), (r1, z1) = wall_at(along - 0.5), wall_at(along + 0.5)
    slope = math.hypot(r1 - r0, z1 - z0)
    wall_r, wall_z = wall_at(along)
    tip_r = wall_r - (z1 - z0) / slope * point_depth(row)
    tip_z = wall_z + (r1 - r0) / slope * point_depth(row)
    if tip_r < 2:
        raise ValueError("The points meet in the middle of the cavity. Lower POINT_DEPTH.")
    return (
        wall_point(tip_r, center, tip_z),
        wall_point(row_radius(row), center - PITCH_DEG / 2, row_z(row)),
        wall_point(row_radius(row - 1), center - lean, row_z(row - 1)),
        wall_point(row_radius(row), center + PITCH_DEG / 2, row_z(row)),
        wall_point(row_radius(row + 1), center + lean, row_z(row + 1)),
    )


def underside_draft():
    """Least lean from vertical, in degrees, of any pyramid's two lower faces.

    Negative means the undersides overhang.
    """
    drafts = []
    for row in range(ROWS + 1):
        tip, left, bottom, right, top = pyramid(row, 0)
        for a, b in ((left, bottom), (bottom, right)):
            normal = (a - tip).cross(b - tip).normalized()
            # Point the normal out of the metal, into the cavity: toward the axis.
            middle = (tip + a + b) / 3
            if normal.dot(Vector(middle.X, middle.Y, 0)) > 0:
                normal = -normal
            drafts.append(math.degrees(math.asin(normal.Z)))
    return min(drafts)


def floor_spikes():
    """Tip and four base corners of each floor spike, on a square grid.

    The grid straddles the axes, so the vent sits in the crease at the middle.
    """
    if not FLOOR_SPIKES:
        return []
    pitch = diamond_width(0)
    height = POINT_DEPTH * pitch
    reach = math.ceil(FLOOR_EDGE / pitch)
    spikes = []
    for i in range(-reach, reach):
        for j in range(-reach, reach):
            x, y = (i + 0.5) * pitch, (j + 0.5) * pitch
            # Keep to the clear floor inside the bottom row's tips. Spikes
            # further out would tangle with the wall's points, where no cutter
            # could separate them.
            clear_r = FLOOR_EDGE - point_depth(0) + pitch / 4
            if math.hypot(abs(x) + pitch / 2, abs(y) + pitch / 2) > clear_r:
                continue
            corners = [
                Vector(x + dx * pitch / 2, y + dy * pitch / 2, 0)
                for dx, dy in ((-1, -1), (1, -1), (1, 1), (-1, 1))
            ]
            spikes.append((Vector(x, y, height), corners))
    return spikes
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

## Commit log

2026-09-30 feat: Initial glass blowing mold design via build123d.
    [flower.step, flower.stl, fluted.step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]
2026-10-08 refactor: Move optic and blow mold outputs into their own folders.
    Each generator now writes to its own folder under mold-designs/, and the
    run instructions in both scripts name the right file.
    [flower.step, flower.stl, fluted.step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]
2026-10-08 feat: Add pineapple mold and swappable-insert mold generator.
    One script builds the pineapple cavity as a solid and as a laser-cut plate
    stack, and an insert mold: four identical loose inserts in a sleeve with a
    tapered bore. Five insert sets fit the same sleeve: pineapple, rings,
    spiral ribs, hobnail and sparse spikes.
    [foot_plate_halves.dxf, foot_plate_solid.dxf, hobnail.step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]
2026-10-08 feat: Add segmented grenade blow mold generator.
    Four identical staves in a length of square steel tube, for a grid of
    raised squares.
    [assembly.step, base_plate.dxf, glass.step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]
2026-10-08 docs: Write README with parts lists and preview pictures.
    Adds render_previews.py, which draws the README pictures from the
    generated STL files.
2026-10-08 fix: Rebuild hobnail insert with whole, individually checked pockets.
    A shop rejected the hobnail insert. Its pockets left stray slivers of flat
    beside them, one row ran off the bottom edge, and cutting all the pockets
    in one go silently left some out.
    Each pocket is now cut on its own and measured, and tried again slightly
    deeper or shallower if the cut does nothing. Pockets that land on a seam
    are cut half into each insert; HOBNAIL_SPLIT_ON_SEAMS = False leaves them
    out instead.
    [foot_plate_halves.dxf, foot_plate_solid.dxf, hobnail.step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]
2026-10-08 build: Add a justfile for regenerating the molds and pictures.
    Each mold recipe is skipped when its files are newer than its script, and
    the pictures are redrawn only when a mold file is newer than they are.
    'just force=true <recipe>' runs regardless.
